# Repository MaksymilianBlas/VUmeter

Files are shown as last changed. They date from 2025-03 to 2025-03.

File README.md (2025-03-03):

# VUmeter
Project with high hopes but never finished.
This was a project to create a VU meter to show something cool to my little brother. The design is made in KiCad, out of 2 PCBs that connect together via a pin header. The bottom PCB is the control circuitry, and the other one (which is vertical) contains rows of LEDs that should light up according to the loudness of the music, as well as a boost converter module. The control circuit has two main parts, a set of eight comparators that indicate the audio level, and eight simple op-amp constant current drivers that get enabled by the comparator outputs and drive the LEDs via a constant current. This was the main improvement over the similar design found in a video by GreatScott (https://www.youtube.com/watch?v=Jyrpx9rEGMI), where the LEDs are supplied from a constant voltage. 
Sadly, two errors have sneaked into the design: Firstly, the logic of the TLV3501 is inverted (it features a Shutdown pin, opposite to the Enable pin of the NCS2002 which was considered at the beginning of the design), and secondly, the comparators are missing pull-up resistors at the outputs (because they are LM393s, which have an open-drain output).
These errors have never been fixed due to lack of time and lost interest. Further possible improvements would be to use dual MOSFETs and quad comparators to save space on the PCB.

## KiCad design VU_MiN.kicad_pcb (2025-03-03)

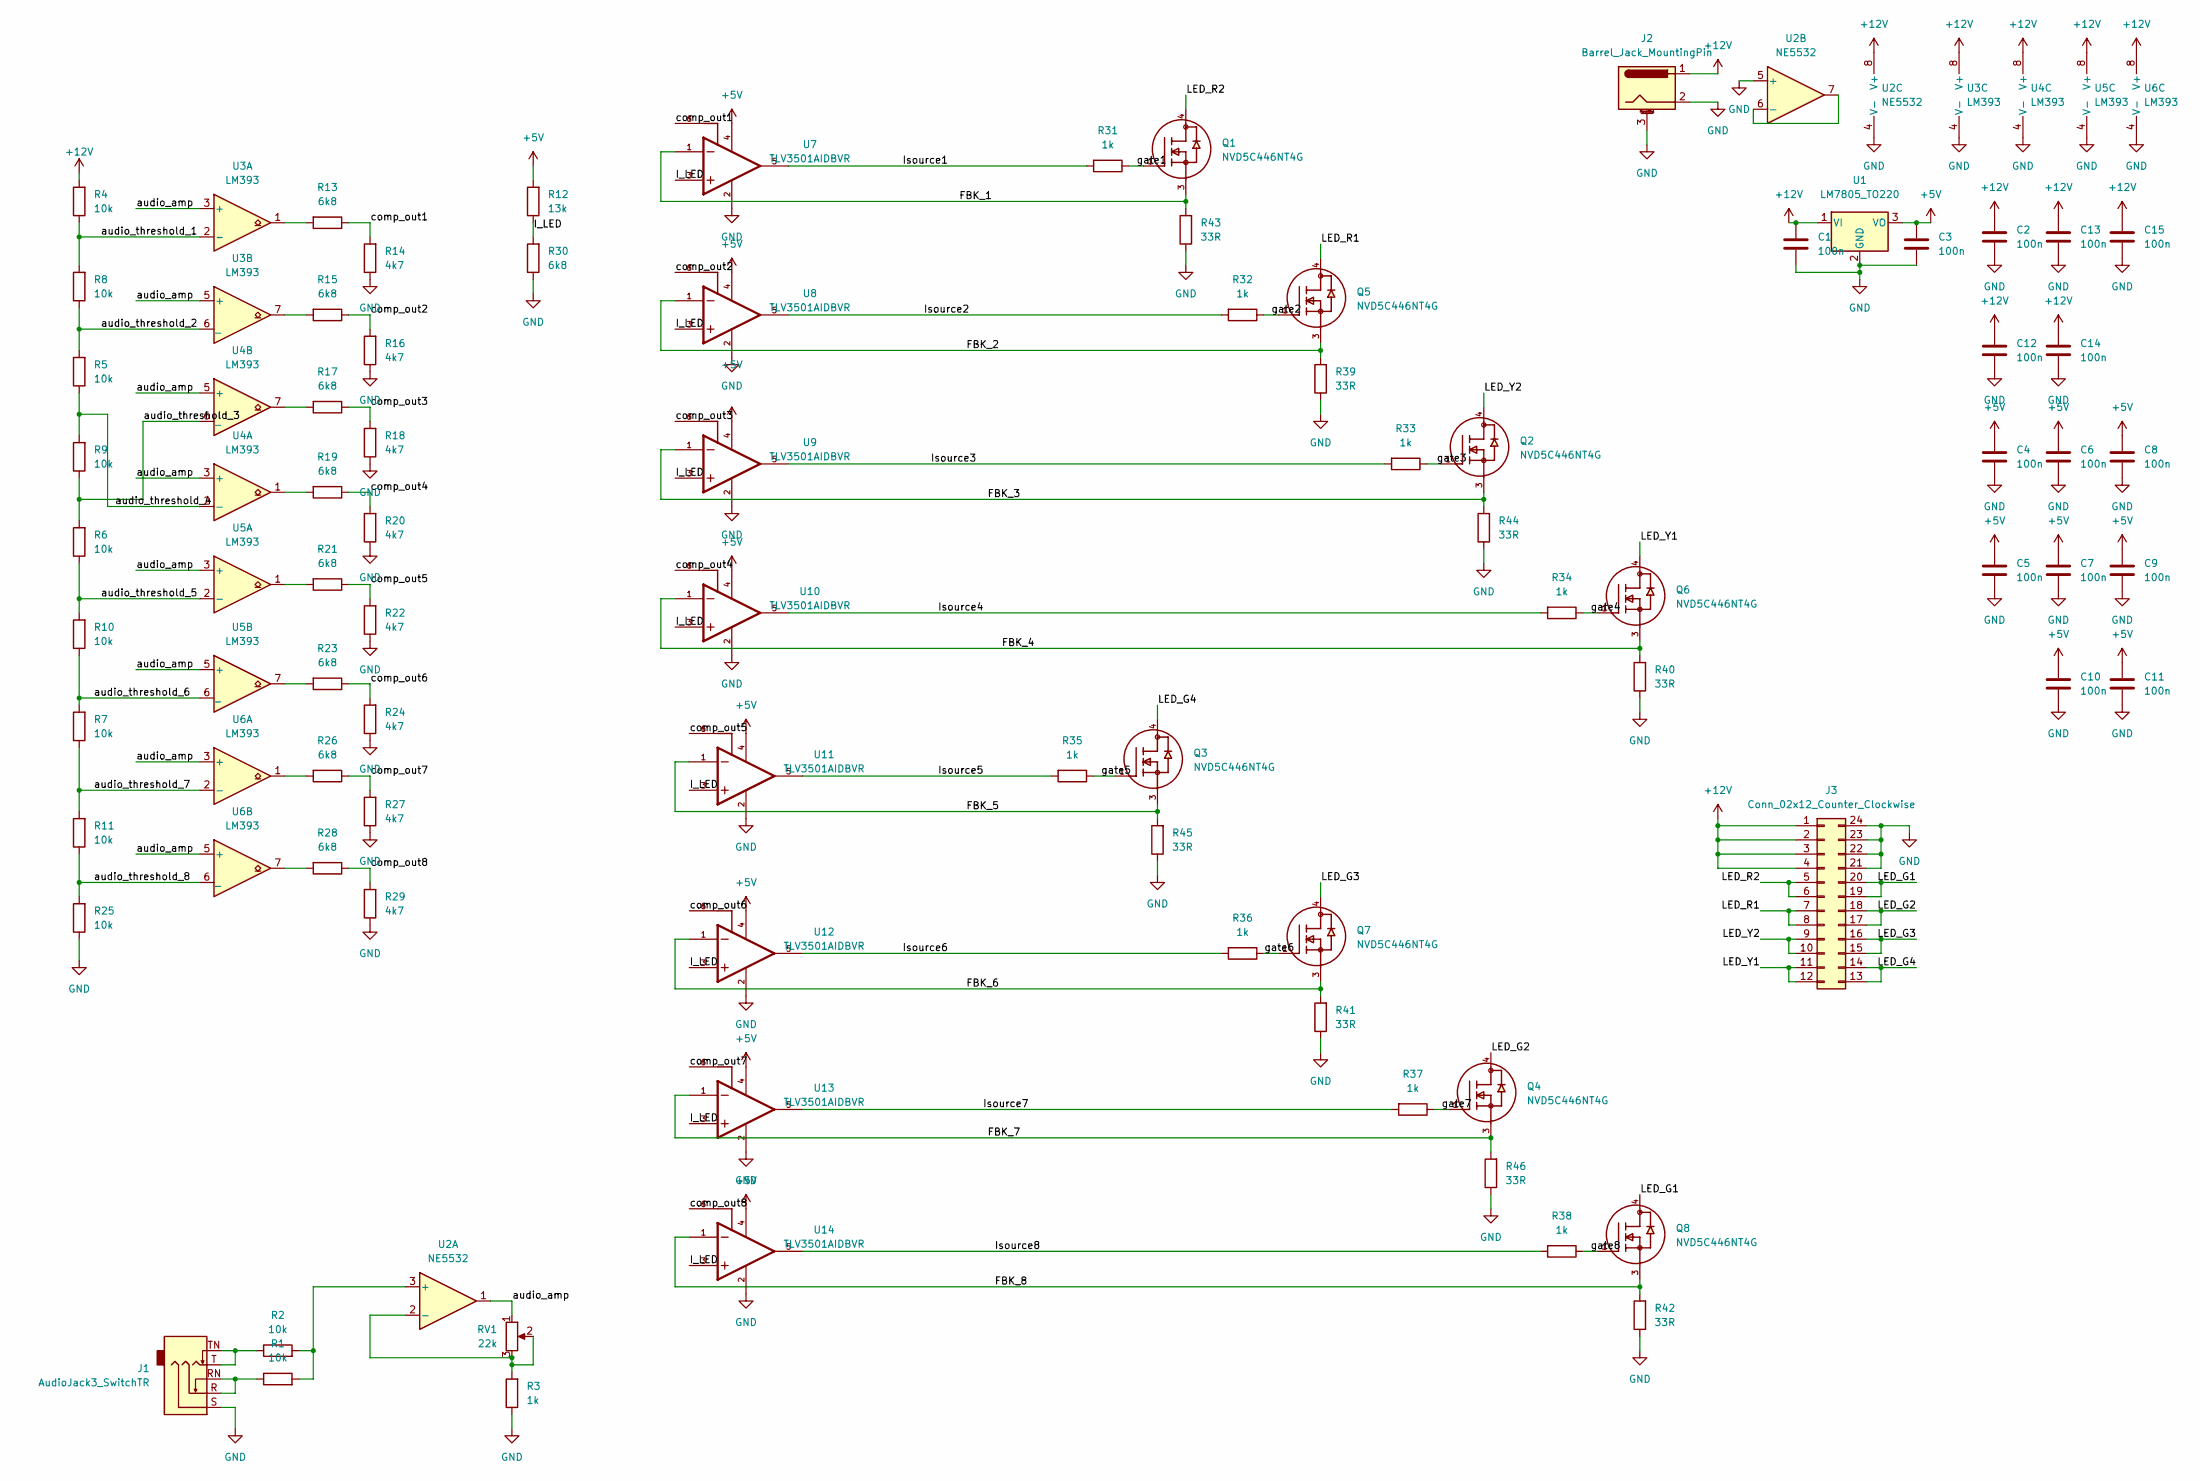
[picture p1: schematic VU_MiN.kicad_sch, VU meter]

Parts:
C1, C2, C3, C4, C5, C6, C7, C8, C9, C10, C11, C12, C13, C14, C15: 100n; C_0603_1608Metric_Pad1.08x0.95mm_HandSolder
J1: AudioJack3_SwitchTR; Jack_3.5mm_Ledino_KB3SPRS_Horizontal
J2: Barrel_Jack_MountingPin; BarrelJack_CUI_PJ-102AH_Horizontal
J3: Conn_02x12_Counter_Clockwise; PinSocket_2x12_P2.54mm_Vertical
Q1, Q2, Q3, Q4, Q5, Q6, Q7, Q8: NVD5C446NT4G; DPAK229P990X238-4N; PARTREV 0
R1, R2, R4, R5, R6, R7, R8, R9, R10, R11, R25: 10k; R_0603_1608Metric_Pad0.98x0.95mm_HandSolder
R3, R31, R32, R33, R34, R35, R36, R37, R38: 1k; R_0603_1608Metric_Pad0.98x0.95mm_HandSolder
R12: 13k; R_0603_1608Metric_Pad0.98x0.95mm_HandSolder
R13, R15, R17, R19, R21, R23, R26, R28, R30: 6k8; R_0603_1608Metric_Pad0.98x0.95mm_HandSolder
R14, R16, R18, R20, R22, R24, R27, R29: 4k7; R_0603_1608Metric_Pad0.98x0.95mm_HandSolder
R39, R40, R41, R42, R43, R44, R45, R46: 33R; R_1210_3225Metric_Pad1.30x2.65mm_HandSolder
RV1: 22k; Potentiometer_Alpha_RD901F-40-00D_Single_Vertical
U1: LM7805_TO220; TO-252-2
U2: NE5532; SOIC-8_3.9x4.9mm_P1.27mm
U3, U4, U5, U6: LM393; SO-8_3.9x4.9mm_P1.27mm
U7, U8, U9, U10, U11, U12, U13, U14: TLV3501AIDBVR; SOT95P280X145-6N; PARTREV E

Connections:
+5V: C3.1, C4.1, C5.1, C6.1, C7.1, C8.1, C9.1, C10.1, C11.1, R12.2, U1.3 (VO), U7.4, U8.4, U9.4, U10.4, U11.4, U12.4, U13.4, U14.4
+12V: C1.1, C2.1, C12.1, C13.1, C14.1, C15.1, J2.1, J3.1, J3.2, J3.3, J3.4, R4.2, U1.1 (VI), U2.8 (V+), U3.8 (V+), U4.8 (V+), U5.8 (V+), U6.8 (V+)
/FBK_1: Q1.3, R43.2, U7.1
/FBK_2: Q5.3, R39.2, U8.1
/FBK_3: Q2.3, R44.2, U9.1
/FBK_4: Q6.3, R40.2, U10.1
/FBK_5: Q3.3, R45.2, U11.1
/FBK_6: Q7.3, R41.2, U12.1
/FBK_7: Q4.3, R46.2, U13.1
/FBK_8: Q8.3, R42.2, U14.1
/I_LED: R12.1, R30.2, U7.3, U8.3, U9.3, U10.3, U11.3, U12.3, U13.3, U14.3
/Isource1: R31.2, U7.5
/Isource2: R32.2, U8.5
/Isource3: R33.2, U9.5
/Isource4: R34.2, U10.5
/Isource5: R35.2, U11.5
/Isource6: R36.2, U12.5
/Isource7: R37.2, U13.5
/Isource8: R38.2, U14.5
/LED_G1: J3.19, J3.20, Q8.4
/LED_G2: J3.17, J3.18, Q4.4
/LED_G3: J3.15, J3.16, Q7.4
/LED_G4: J3.13, J3.14, Q3.4
/LED_R1: J3.7, J3.8, Q5.4
/LED_R2: J3.5, J3.6, Q1.4
/LED_Y1: J3.11, J3.12, Q6.4
/LED_Y2: J3.9, J3.10, Q2.4
/audio_amp: RV1.1, U2.1, U3.3 (+), U3.5 (+), U4.3 (+), U4.5 (+), U5.3 (+), U5.5 (+), U6.3 (+), U6.5 (+)
/audio_threshold_1: R4.1, R8.2, U3.2 (-)
/audio_threshold_2: R5.2, R8.1, U3.6 (_)
/audio_threshold_3: R6.2, R9.1, U4.6 (_)
/audio_threshold_4: R5.1, R9.2, U4.2 (-)
/audio_threshold_5: R6.1, R10.2, U5.2 (-)
/audio_threshold_6: R7.2, R10.1, U5.6 (_)
/audio_threshold_7: R7.1, R11.2, U6.2 (-)
/audio_threshold_8: R11.1, R25.2, U6.6 (_)
/comp_out1: R13.1, R14.2, U7.6
/comp_out2: R15.1, R16.2, U8.6
/comp_out3: R17.1, R18.2, U9.6
/comp_out4: R19.1, R20.2, U10.6
/comp_out5: R21.1, R22.2, U11.6
/comp_out6: R23.1, R24.2, U12.6
/comp_out7: R26.1, R27.2, U13.6
/comp_out8: R28.1, R29.2, U14.6
/gate1: Q1.1, R31.1
/gate2: Q5.1, R32.1
/gate3: Q2.1, R33.1
/gate4: Q6.1, R34.1
/gate5: Q3.1, R35.1
/gate6: Q7.1, R36.1
/gate7: Q4.1, R37.1
/gate8: Q8.1, R38.1
GND: C1.2, C2.2, C3.2, C4.2, C5.2, C6.2, C7.2, C8.2, C9.2, C10.2, C11.2, C12.2, C13.2, C14.2, C15.2, J1.S, J2.2, J2.3 (MountPin), J3.21, J3.22, J3.23, J3.24, R3.1, R14.1, R16.1, R18.1, R20.1, R22.1, R24.1, R25.1, R27.1, R29.1, R30.1, R39.1, R40.1, R41.1, R42.1, R43.1, R44.1, R45.1, R46.1, U1.2 (GND), U2.4 (V-), U2.5 (+), U3.4 (V-), U4.4 (V-), U5.4 (V-), U6.4 (V-), U7.2, U8.2, U9.2, U10.2, U11.2, U12.2, U13.2, U14.2
unnamed: J1.R, J1.RN, R1.1
unnamed: J1.T, J1.TN, R2.1
unnamed: R1.2, R2.2, U2.3 (+)
unnamed: R3.2, RV1.2, RV1.3, U2.2 (-)
unnamed: R13.2, U3.1
unnamed: R15.2, U3.7
unnamed: R17.2, U4.7
unnamed: R19.2, U4.1
unnamed: R21.2, U5.1
unnamed: R23.2, U5.7
unnamed: R26.2, U6.1
unnamed: R28.2, U6.7
unnamed: U2.6 (-), U2.7

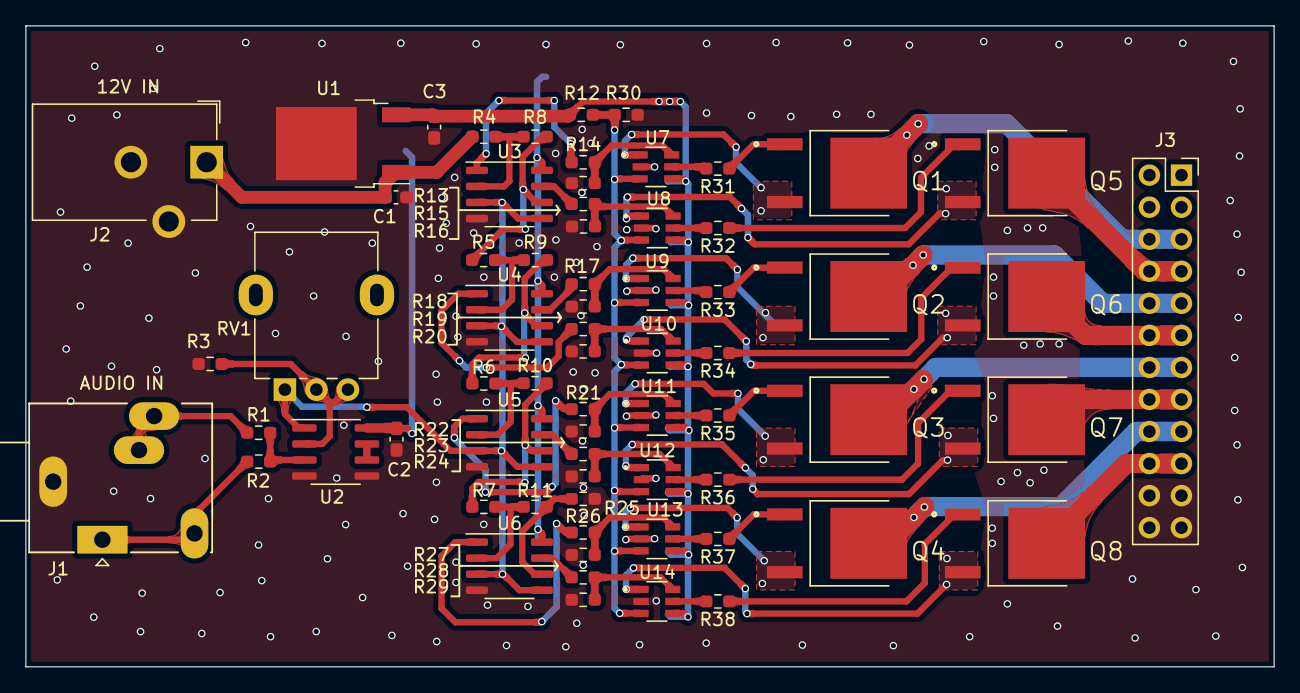
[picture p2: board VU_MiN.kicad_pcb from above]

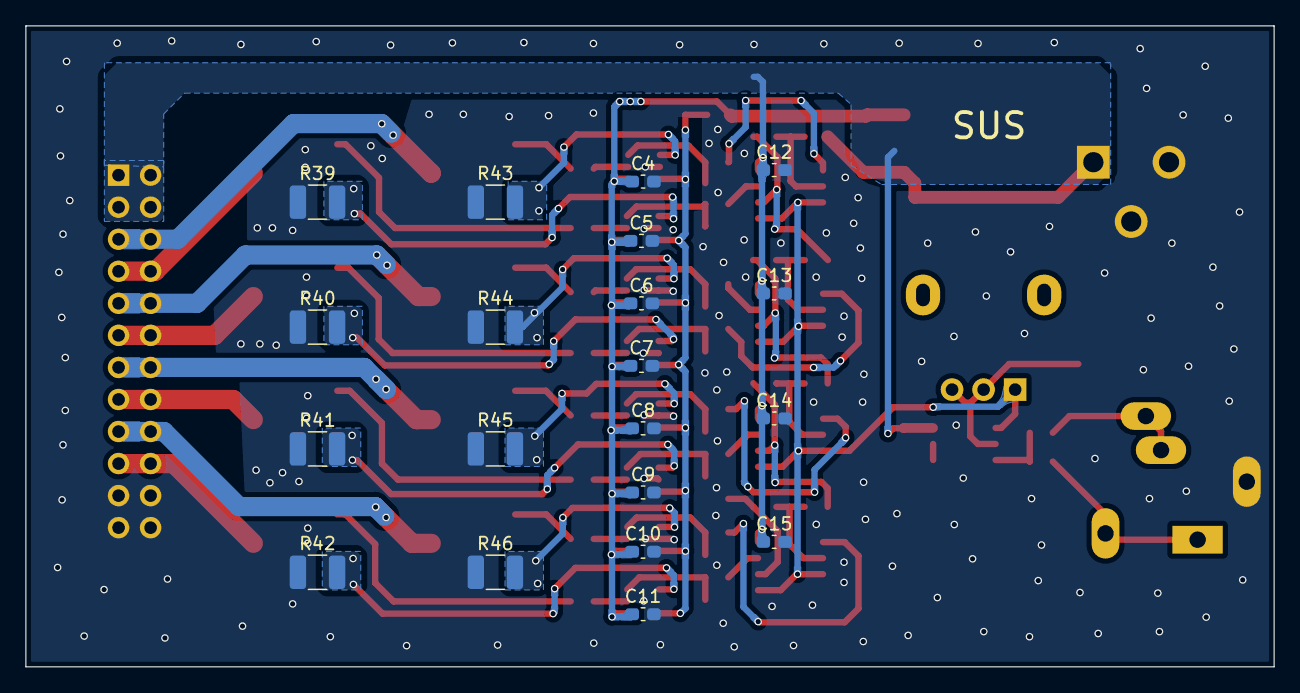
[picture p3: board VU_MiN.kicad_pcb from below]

Board: 2 copper layers, 98.9 x 50.8 mm, 87 parts (20 on the bottom side), 66 nets.

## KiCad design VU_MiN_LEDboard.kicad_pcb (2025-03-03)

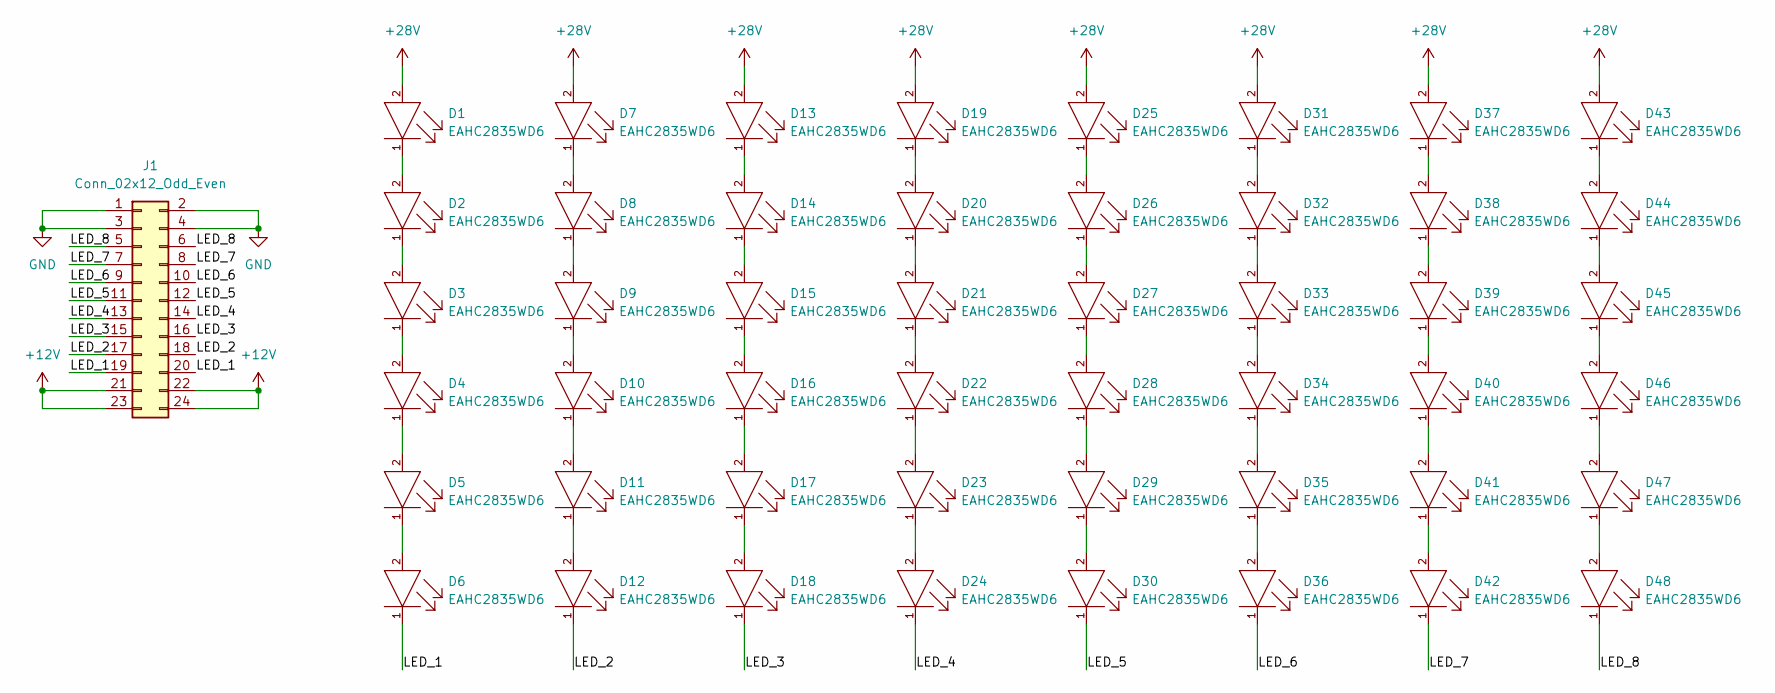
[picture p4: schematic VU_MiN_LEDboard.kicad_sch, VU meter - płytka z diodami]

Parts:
D1, D2, D3, D4, D5, D6, D7, D8, D9, D10, D11, D12, D13, D14, D15, D16, D17, D18, D19, D20, D21, D22, D23, D24, D25, D26, D27, D28, D29, D30, D31, D32, D33, D34, D35, D36, D37, D38, D39, D40, D41, D42, D43, D44, D45, D46, D47, D48: EAHC2835WD6; Everlight-EAHC2835WD6-MFG; forward voltage 3.4V; reverse voltage 5V; mouser part number 638-EAHC2835WD6; digikey description LED COOL WHITE 6500K 2SMD
J1: Conn_02x12_Odd_Even; PinHeader_2x12_P2.54mm_Horizontal

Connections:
+12V: J1.21, J1.22, J1.23, J1.24; also elsewhere on the board
+28V: D1.2 (ANODE), D7.2 (ANODE), D13.2 (ANODE), D19.2 (ANODE), D25.2 (ANODE), D31.2 (ANODE), D37.2 (ANODE), D43.2 (ANODE)
/LED_1: D6.1 (CATHODE), J1.19, J1.20
/LED_2: D12.1 (CATHODE), J1.17, J1.18
/LED_3: D18.1 (CATHODE), J1.15, J1.16
/LED_4: D24.1 (CATHODE), J1.13, J1.14
/LED_5: D30.1 (CATHODE), J1.11, J1.12
/LED_6: D36.1 (CATHODE), J1.9, J1.10
/LED_7: D42.1 (CATHODE), J1.7, J1.8
/LED_8: D48.1 (CATHODE), J1.5, J1.6
GND: J1.1, J1.2, J1.3, J1.4
unnamed: D1.1 (CATHODE), D2.2 (ANODE)
unnamed: D2.1 (CATHODE), D3.2 (ANODE)
unnamed: D3.1 (CATHODE), D4.2 (ANODE)
unnamed: D4.1 (CATHODE), D5.2 (ANODE)
unnamed: D5.1 (CATHODE), D6.2 (ANODE)
unnamed: D7.1 (CATHODE), D8.2 (ANODE)
unnamed: D8.1 (CATHODE), D9.2 (ANODE)
unnamed: D10.1 (CATHODE), D11.2 (ANODE)
unnamed: D9.1 (CATHODE), D10.2 (ANODE)
unnamed: D11.1 (CATHODE), D12.2 (ANODE)
unnamed: D13.1 (CATHODE), D14.2 (ANODE)
unnamed: D14.1 (CATHODE), D15.2 (ANODE)
unnamed: D15.1 (CATHODE), D16.2 (ANODE)
unnamed: D16.1 (CATHODE), D17.2 (ANODE)
unnamed: D17.1 (CATHODE), D18.2 (ANODE)
unnamed: D19.1 (CATHODE), D20.2 (ANODE)
unnamed: D20.1 (CATHODE), D21.2 (ANODE)
unnamed: D21.1 (CATHODE), D22.2 (ANODE)
unnamed: D22.1 (CATHODE), D23.2 (ANODE)
unnamed: D23.1 (CATHODE), D24.2 (ANODE)
unnamed: D25.1 (CATHODE), D26.2 (ANODE)
unnamed: D26.1 (CATHODE), D27.2 (ANODE)
unnamed: D27.1 (CATHODE), D28.2 (ANODE)
unnamed: D28.1 (CATHODE), D29.2 (ANODE)
unnamed: D29.1 (CATHODE), D30.2 (ANODE)
unnamed: D31.1 (CATHODE), D32.2 (ANODE)
unnamed: D32.1 (CATHODE), D33.2 (ANODE)
unnamed: D33.1 (CATHODE), D34.2 (ANODE)
unnamed: D34.1 (CATHODE), D35.2 (ANODE)
unnamed: D35.1 (CATHODE), D36.2 (ANODE)
unnamed: D37.1 (CATHODE), D38.2 (ANODE)
unnamed: D38.1 (CATHODE), D39.2 (ANODE)
unnamed: D39.1 (CATHODE), D40.2 (ANODE)
unnamed: D40.1 (CATHODE), D41.2 (ANODE)
unnamed: D41.1 (CATHODE), D42.2 (ANODE)
unnamed: D43.1 (CATHODE), D44.2 (ANODE)
unnamed: D44.1 (CATHODE), D45.2 (ANODE)
unnamed: D45.1 (CATHODE), D46.2 (ANODE)
unnamed: D46.1 (CATHODE), D47.2 (ANODE)
unnamed: D47.1 (CATHODE), D48.2 (ANODE)

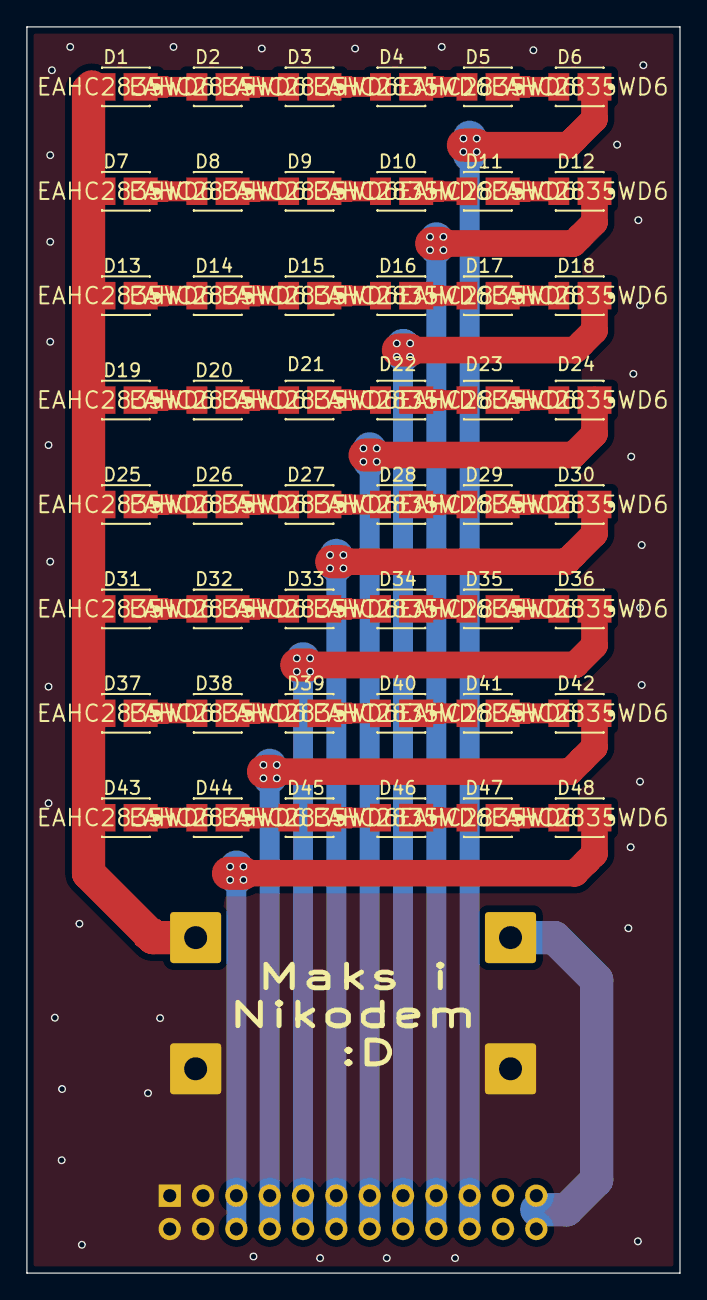
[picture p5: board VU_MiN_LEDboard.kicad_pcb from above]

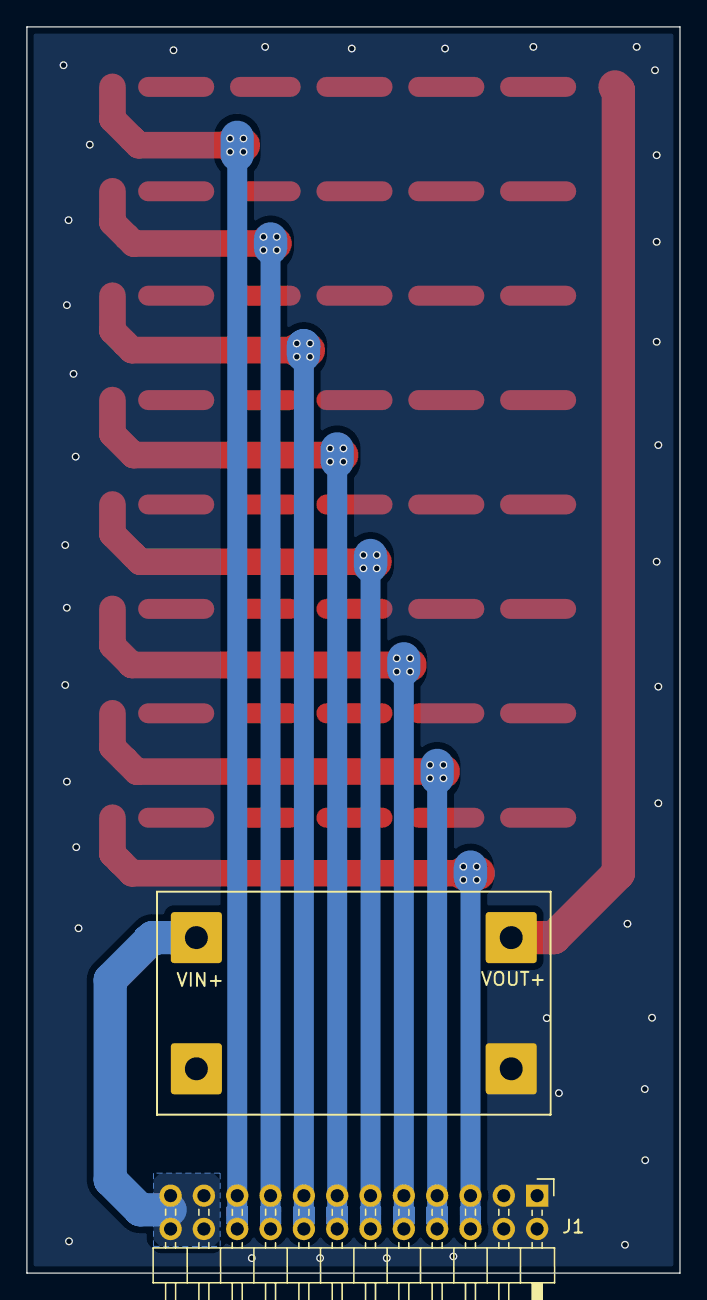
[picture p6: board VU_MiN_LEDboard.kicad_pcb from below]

Board: 2 copper layers, 49.8 x 95.0 mm, 50 parts (2 on the bottom side), 51 nets.

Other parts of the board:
VOUT+: SolderWire-1sqmm_1x01_D1.4mm_OD3.9mm

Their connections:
+12V: VOUT+.1; also elsewhere on the board

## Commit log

2025-03-03 Add files via upload
    Add project files for the LED PCB.
    [VU_MiN_LEDboard.kicad_pcb, VU_MiN_LEDboard.kicad_sch]
2025-03-03 Add files via upload
    Add project files for controll PCB.
    [VU_MiN.kicad_pcb, VU_MiN.kicad_sch]
